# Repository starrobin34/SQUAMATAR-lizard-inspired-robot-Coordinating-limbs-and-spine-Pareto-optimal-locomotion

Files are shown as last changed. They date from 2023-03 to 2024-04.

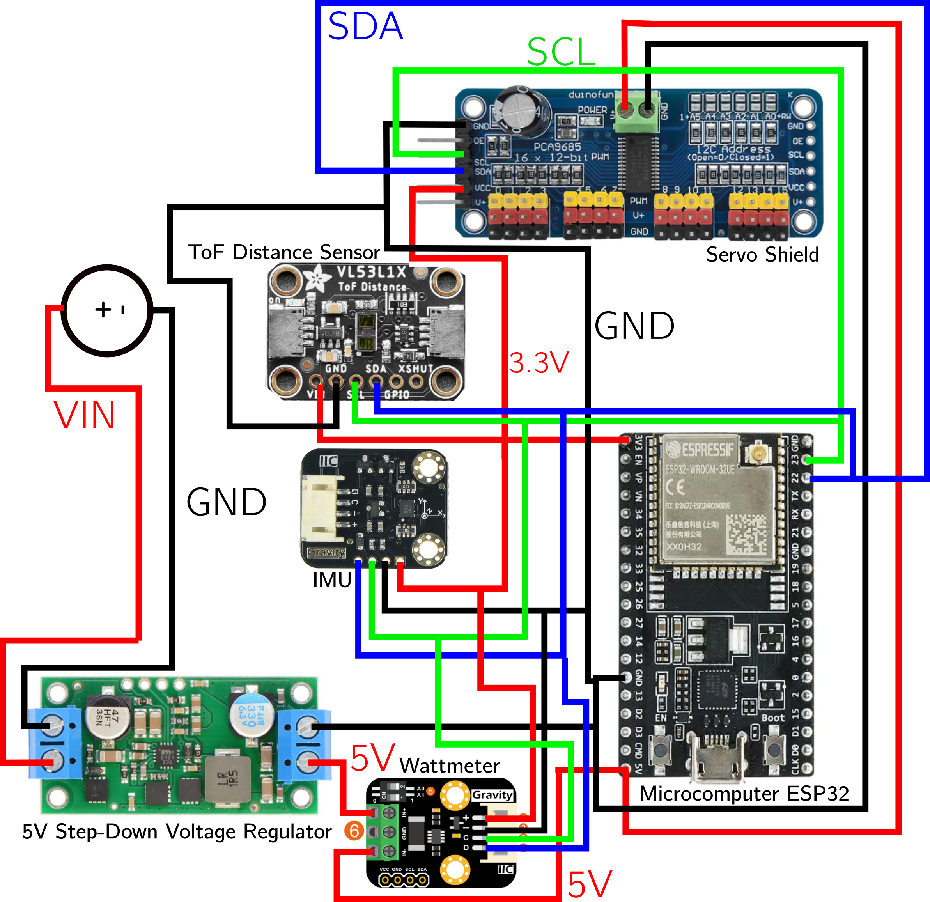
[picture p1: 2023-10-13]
Circuit_schematics/Circuit_Schematics.png

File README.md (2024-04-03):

# Introduction
We establish a lizard inspired quadrupedal robot which is able to walk on flat surfaces and climb on inclined or horizontal textured walls using claws. 
This repository contains supplementary videos for the publication Rockenfeller et al., 2024 titled "Coordinating limbs and spine: (Pareto-)optimal locomotion in theory, in vivo, and in robots" published in .... 

https://github.com/starrobin34/SQUAMATAR-lizard-inspired-robot-Coordinating-limbs-and-spine-Pareto-optimal-locomotion/assets/82499284/5d567510-2994-403e-8367-0f4579b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

Key features 
- **Measure stride distance**
- **Measure time per stride**
- **Measure current consumption**
- **Accelerometer data**
- **Adjustable gait parameters: ROM, Wrist angles etc.**
- **Interchangeable leg length**

# Comparison lizards, model and robot configurations  

https://github.com/starrobin34/SQUAMATAR-lizard-inspired-robot-Coordinating-limbs-and-spine-Pareto-optimal-locomotion/assets/82499284/a11de8b8-b702-45a9-a864-d049114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

# Overstepping 
Lizards were able to outperform the model predictions and the performance of the robot. We suggest this is due to the lizards overstepping their hindlimbs e.g. placing them at the same spot or in front of their fore limbs. 
This is physically not possible for the robot and a geometric limitation of the model. 

https://github.com/starrobin34/SQUAMATAR-lizard-inspired-robot-Coordinating-limbs-and-spine-Pareto-optimal-locomotion/assets/82499284/ca8f6793-2c17-4a9e-8aff-b4e42e7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

# Citation

R. Rockenfeller et al., "*Coordinating limbs and spine: (Pareto-)optimal locomotion in theory, in vivo, and in robots*," 
```
@article{Rockenfeller2024,  
	author={},  
	booktitle={},   
	title={},   
	year={},   
	pages={},  
	doi={}}

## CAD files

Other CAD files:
CAD/12Channel PWM.ipt
CAD/Ball_Gearing_Workaroung.ipt
CAD/Battery_holder.ipt
CAD/Battery_holder_V2.ipt
CAD/Battery_holder_longer_part.ipt
CAD/Bendable_Spine.ipt
CAD/CJMCU-219 INA219 v13 v1.ipt
CAD/CJMCU-219 INA219 v13.ipt
CAD/CJMCU-219 INA219.ipt
CAD/CJMCU.ipt
CAD/Carbon_Fiber_Tube_70mm.ipt
CAD/Carbon_Fiber_Tube_70mm_MIR.ipt
CAD/Carbon_Fiber_Tube_70mm_MIR1.ipt
CAD/Carbon_Fiber_Tube_70mm_MIR2.ipt
CAD/Carbon_Fiber_Tube_70mm_MIR2_MIR.ipt
CAD/Carbon_Fiber_Tube_70mm_MIR2_MIR1.ipt
CAD/Carbon_Fiber_Tube_70mm_MIR2_MIR1_MIR.ipt
CAD/Carbon_Fiber_Tube_70mm_MIR2_MIR2.ipt
CAD/Carbon_Fiber_Tube_70mm_MIR3.ipt
CAD/Carbon_Fiber_Tube_70mm_MIR3_MIR.ipt
CAD/Carbon_Fiber_Tube_70mm_MIR4.ipt
CAD/Carbon_Fiber_Tube_70mm_MIR_MIR.ipt
CAD/Carbon_Fiber_Tube_middle.ipt
CAD/Coffein.ipt
CAD/DMS90_Bottom_Plate.ipt
CAD/DMS90_Bottom_Plate_MIR.ipt
CAD/DMS90_Bottom_Plate_MIR1.ipt
CAD/DMS90_Bottom_Plate_MIR1_MIR.ipt
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

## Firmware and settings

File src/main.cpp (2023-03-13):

/* Main Arduino Sketch 
*/

#include <Arduino.h>
#include <Wire.h>
#include <sensor_functions.h>
#include <gaits.h> 
#include <webinterface.h>

void setup() {
  Serial.begin(115200);
  while (!Serial)
  delay(1000);
  Serial.println("Serial is up.");
  Wire.begin(); 
  pinMode(GPIO_NUM_4, OUTPUT);

//Wifi 
/* Go to http://192.168.4.1 in a web browser
   connected to the ESP AP to see the webinterface 
*/
  Serial.print("Setting AP (Access Point)…");
  WiFi.softAP(ssid);
  IPAddress IP = WiFi.softAPIP();
  Serial.print("AP IP address: ");
+  Serial.println(IP);

  //callback functions for http requests  
  server.on("/", handle_root); 
  server.on("/X5_juggernaut.csv", download_data); 
  server.begin();

  //Initialize/Settings I2C Devices
  pwm.begin();
  pwm.setPWMFreq(60);

  //Current sensor 
  Serial.begin(115200);
  while(!Serial);
  Serial.println();
  while(ina219.begin() != true) {
    Serial.println("INA219 begin failed");
    delay(2000);
  }
  ina219.linearCalibrate(ina219Reading_mA, extMeterReading_mA);
  Serial.println();

  //distance Sensor 
  if (! vl53.begin(0x29, &Wire)) {
    Serial.print(F("Error on init of VL sensor: "));
    Serial.println(vl53.vl_status);
    while (1)       delay(10);
  }
  if (! vl53.startRanging()) {
    Serial.print(F("Couldn't start ranging: "));
    Serial.println(vl53.vl_status);
    while (1)       delay(10);
  }

  vl53.setTimingBudget(100); // Valid timing budgets: 15, 20, 33, 50, 100, 200 and 500ms!
  vl53.VL53L1X_SetDistanceMode(2); //2 = long, 1=short

  //Gyro 
  if (bmi160.softReset() != BMI160_OK){
    Serial.println("reset false");
    while(1);
  }
  //set and init the bmi160 i2c address
  if (bmi160.I2cInit(i2c_addr) != BMI160_OK){
    Serial.println("init false");
    while(1);
  }

  home_pos(); //All Servos to home position 

  for (size_t i = 0; i < 5; i++) //blink led 
  {
    digitalWrite(GPIO_NUM_4, HIGH);
    delay(100);
    digitalWrite(GPIO_NUM_4, LOW);
    delay(100); 
  }
  delay(1000); 
}

void loop() {
  server.handleClient(); 
}

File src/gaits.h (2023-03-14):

/* 
  this File contains all Variables and functions for the Servo movement and the gaits 
*/

//Define Max and Min Pulsewidth of Batan Servo (Feet)
#define datan_servo_min 112 //30
#define datan_servo_max 460 //150 degrees
//Define the max and min Signal for feedback of Datan Servo 
#define datan_feedback_min 540 //30 degrees 
#define datan_feedback_max 2329 //150 degrees 

//Define Max and Min Pulsewidth of DSS Servo (Spine and Shoulder)
#define dss_servo_min 468 //30
#define dss_servo_max 242 //150 degrees
//Define the max and min Signal for feedback of DSS Servo 
#define dss_feedback_min 2420 //30 degrees 
#define dss_feedback_max 881 //150 degrees 

//Define Max and Min Pulsewidth of DMS Servo (Wrist)
#define dms_servo_min 615
#define dms_servo_max 100
//Define the max and min Signal for feedback of DMS Servo 
#define dms_feedback_min 3076 //30 degrees 
#define dms_feedback_max 1612 //150 degrees 

//Define Motor Slot Number on PCA9685 (Servo Shield)
const int lff = 4; // Left front foot 
const int lfs = 0; //left front shoulder
const int rfs = 1; //right front shoulder 
const int rff = 5; //right front foot
const int f_s = 2; //front spine 
const int h_s = 13; //hind spine 
const int rhf = 6; //right hind foot
const int rhs = 14; //right hind shoulder 
const int lhs = 15; //left hind shoulder 
const int lhf = 7; //left hind foot
const int lfa = 9; //Left front Wrist Angle 
const int rfa = 8; //Right Front Wrist Angle 
const int lha = 10; //Left hind Wrist angle 
const int rha = 11; //Right hind Wrist Angle 

//Define Feedback pins for Servos 
const int f_s_feed = GPIO_NUM_34; //front spine 
const int h_s_feed = GPIO_NUM_35; //hind spine 
const int lfs_feed = GPIO_NUM_34; //left front shoulder !!!!!!!!!!!!!CHANGE
const int rfs_feed = GPIO_NUM_32; //right front shoulder
const int rfa_feed = GPIO_NUM_33; //Right Front Wrist Angle  
// const int lfa_feed = GPIO_NUM_33; //Left front Wrist Angle
const int rff_feed = GPIO_NUM_39; 
const int lhf_feed = GPIO_NUM_36;

//Input Variables for motion --> adjustable in web interface  
int rom_spine = 10; //range of motion of spine
int rom_limb = 10; //range of motion of legs 
int rom_feet = 75; //range of motion of feet 
int dynamic = 1; //defines which dynamic to use (1 = sigmoid, 2 = sinusoid) 
int gait = 0;  // defines which gait to use (0, no gait, 1 = regular gait, 2 turn gait (NOT YET IMPLEMENTED)) 
int speed_val = 15; //(15 Standard) Speed of leg and spine (changes the delay between each increment in microseconds)
int speed_val_foot = 15; // defines the speed for lifting the feet (changes the delay between each increment in microseconds)
int number_of_steps = 11; //number of full steps to be taken 
int foot_center= 0; //defines the offset of the angle of the feet to the vertical to the ground axis 
int front_leg_center = 0; //defines the center where the middle of the range of motion lies (frontlegs)
int hind_leg_center = 0; //defines the center where the middle of the range of motion lies (backlegs)
int front_wrist_angle = 0; //defines the orientation of the front foot( + for positive angle from axis, - for negative angle from axis) 
int hind_wrist_angle = 0; //defines the orientation of the hind foot ( + for positive angle from axis, - for negative angle from axis) 
int dynamic_wrist_angle = 1; //defines if dynamically counteracting Wrist angle is used (0 = not used, 1 = counteracting by angle,  2 = counteracting by reading analog pins (NOT YET IMPLEMENTED)) 

//Input Variables for motion (not adjustable in web interface) 
int resolution_dynamic_functions = 50; //increments for the dynamic functions 
int rom_wrist_angle = rom_spine + rom_limb; 

//information variables  
int climb_incline = 90; 
String claw_angle = "10", surface = "coarse_carpet", toe_angle = "0", robot = "X5_Juggernaut";
float leg_length = 105, spine_length = 315, spine_middle = 181, should_offset = 45; 
float spine_front = (spine_length - spine_middle) / 2;  

//Variables for Data Collection 
float elapsed_time[11] =  {0.0}; //time of step in s 
int stride[11] = {1, 2, 3, 4, 5, 6, 7, 8, 9, 10, 11}; 
int distance[11] = {0}; //sum covered distance in mm 
//accelerometer/gyro 
float mean_acc_xaxis[11] =  {0.0};
float mean_acc_yaxis[11] = {0.0};
float mean_acc_zaxis[11] = {0.0};
float angle_yaxis[11] = {0.0}; //acc at end of stride ---> for calculation of angle 
float angle_zaxis[11] = {0.0}; //acc at end of stride ---> for calculation of angle 
float xaxis_during_stride [10] = {0.0}; 
float yaxis_during_stride [10] = {0.0};
float zaxis_during_stride [10] = {0.0};
float xaxis_sum, yaxis_sum, zaxis_sum;
//current measurements
float mean_current[11] = {0.0}; //average current consumption per stride in A
float max_current [11] = {0.0};//displays maximal current spike in a stride in A 
float current_during_stride [10] = {0.0}; //stores current values of a stride, size displays number of measurements per stride
float curr_sum;
int curr_index = 0; 
//Servo Success in % e.g. did Servo reach the desired position 
int lff_suc[11] = {0}; // Left front foot 
int lfs_suc[11] = {0}; //left front shoulder
int rfs_suc[11] = {0}; //right front shoulder 
int rff_suc[11] = {0}; //right front foot
int f_s_suc[11] = {0}; //front spine 
int h_s_suc[11] = {0}; //hind spine 
int rhf_suc[11] = {0}; //right hind foot
int rhs_suc[11] = {0}; //right hind shoulder 
int lhs_suc[11] = {0}; //left hind shoulder 
int lhf_suc[11] = {0}; //left hind foot
int lfa_suc[11] = {0}; //Left front Wrist Angle 
int rfa_suc[11] = {0}; //Right Front Wrist Angle 
int lha_suc[11] = {0}; //Left hind Wrist angle 
int rha_suc[11] = {0}; //Right hind Wrist Angle 

bool interrupt_mid_stride = false;

//function prototypes 
void move_motor(int motor_num, int angle); //move Servo certain angle 
void home_pos(); //returns all Servos to home position  
int dynamic_movement_spine(int increment);  //dynamic function for spine 
int dynamic_movement_legs(int increment); //dynamic function for legs
int dynamic_movement_feet(int increment); 
void gait1(); 
int sensor_to_angle(int motor_num, int feedback_pin); //convert sensor reading to angle
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

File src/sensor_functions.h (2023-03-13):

/* 
  this File contains the sensor functions 
*/

#include <Wire.h>
#include <Adafruit_PWMServoDriver.h>
#include "Adafruit_VL53L1X.h"
#include "DFRobot_INA219.h"
#include <DFRobot_BMI160.h>


Adafruit_VL53L1X vl53 = Adafruit_VL53L1X();
Adafruit_PWMServoDriver pwm = Adafruit_PWMServoDriver(0x40);
DFRobot_INA219_IIC ina219(&Wire, INA219_I2C_ADDRESS4);
DFRobot_BMI160 bmi160;
const int8_t i2c_addr = 0x69;

// Revise the following two paramters according to actual reading of the INA219 and the multimeter
// for linearly calibration
float ina219Reading_mA = 1000;
float extMeterReading_mA = 1000;

float y_ang_offset = 0.0, z_ang_offset = 0.0, x_acc_offset = 0.0, y_acc_offset = 0.0, z_acc_offset = 0.0;  

int step_val = 0; 
bool interrupt = false; 

int get_dist(); 
float get_current(); 
float get_accel(int val); 


int get_dist(){ 

  int measured_dist; 
  int sample_size = 10;
  int sum = 0;  
  int mean_dist; 

  measured_dist = vl53.distance();
  // Serial.println(measured_dist); 

  if (measured_dist <= 230 && measured_dist > 0)
  {
    interrupt = true; 
    // Serial.println(measured_dist); 
    // Serial.println("End of track reached!"); 
  }

  if (measured_dist == -1) //input max reading of sensor here/fall value 
  {
    interrupt = true; 
    // Serial.println(measured_dist); 
    // Serial.println("Distance sensor read max!"); 
    measured_dist = 9999; 
    return measured_dist;
  }

  for (size_t i = 0; i < sample_size; i++)
  {
    sum += vl53.distance();
    delay(1); 
  }
  mean_dist = sum / sample_size; 
  return mean_dist;
}

float get_current(){ 

  float current; 
  current = ina219.getCurrent_mA(); 
  
  return current; 
}

float get_accel(int val){ 
  
  float measured_xaxisValue, measured_yaxisValue, measured_zaxisValue;
  float z_angle, y_angle; 
  int rslt;
  int16_t accelGyro[6]={0}; 
  float rad_to_deg = 180 / PI;

  // //Mean for more precision --> SLOWER !! 
  // float x[5] = {0.0}; //arrays to store acceleration in X, Y, Z 
  // float y[5] = {0.0};
  // float z[5] = {0.0};

  // for (size_t i = 0 ; i < 5; i++) {
  //   rslt = bmi160.getAccelGyroData(accelGyro); //SLOW !!!
  //       x[i] = accelGyro[3]/16384.0; //get linear acceleration in g-force 
  //       y[i] = accelGyro[4]/16384.0; 
  //       z[i] = accelGyro[5]/16384.0;   
  // }

  // measured_xaxisValue = (x[0] + x[1] + x[2] + x[3] + x[4]) / 5; //Mean to reduce influence of noise of the sensor
  // measured_yaxisValue = (y[0] + y[1] + y[2] + y[3] + y[4]) / 5;
  // measured_zaxisValue = (z[0] + z[1] + z[2] + z[3] + z[4]) / 5;

  //No mean 
  rslt = bmi160.getAccelGyroData(accelGyro);
  if (rslt == 0)
  {
  measured_xaxisValue = accelGyro[3]/16384.0;
  measured_yaxisValue = accelGyro[4]/16384.0;
  measured_zaxisValue = accelGyro[5]/16384.0;
  }
  
  if (val == 1)
  {
    return measured_xaxisValue; 
  }
    if (val == 2)
  {
    return measured_yaxisValue; 
  }
    if (val == 3)
  {
    return measured_zaxisValue; 
  }
  if (val == 4)
  {
    y_angle = (rad_to_deg * (atan2(measured_yaxisValue, measured_xaxisValue))) - y_ang_offset;
    return y_angle; 
  }
  if (val == 5)
  {
    z_angle = (rad_to_deg * (atan2(-measured_zaxisValue, measured_xaxisValue))) - z_ang_offset; 
    return z_angle; 
  }
  
  return 0.0; 
}

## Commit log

2022-11-08 working but buggy website
    [gaits.h, main.cpp, sensor_functions.h]
2022-11-30 All Sensors working/Website little buggy
    [gaits.h, main.cpp, sensor_functions.h]
2023-02-16 Wrist angle correction working
    [gaits.h, main.cpp, sensor_functions.h]
2023-02-16 accel during step fixed
    [gaits.h, sensor_functions.h]
2023-03-13 final half step fix
    [gaits.h, sensor_functions.h]
2023-10-13 add CAD and circuit schematics
    [12Channel PWM.ipt, Ball_Gearing_Workaroung.ipt, Battery_holder.ipt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]
